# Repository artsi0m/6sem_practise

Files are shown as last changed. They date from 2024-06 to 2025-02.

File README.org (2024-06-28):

**  PCB project of RS485 — RS232 converter from 6 semester practise in BSUIR

| Folder             | Сontent                                      |
| kicad-rs-converter | PCB project in KiCAD                         |
| paper              | practise report                              |
| SEL                | structured element list (Перечень элементов) |

*** Original schematic

Original schematic was brought from Radio Locman magizine:
https://www.radiolocman.com/shem/schematics.html?di=64700
But DB9 connector was excluded.

Оригинальная схема была взята из журнала Радио Лоцман:
https://www.rlocman.ru/shem/schematics.html?di=64700
Однако разъём DB9 не использовался.

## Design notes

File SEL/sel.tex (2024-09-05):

\documentclass{xesel}
\usepackage{polyglossia}
\setdefaultlanguage{russian}
\setotherlanguage{english}
\defaultfontfeatures{Mapping=tex-text}
\setmainfont[AutoFakeSlant=0.25,AutoFakeBold=0.2,Scale=0.85]{OpenGost Type A TT}
\begin{document}
\XeselDesignedBy{Корякин А.Л. }
\XeselCheckedBy{Дубровский В.В. }
\XeselDocumentNumber{465223.013 ПЭ3}
\XeselDocumentName{Конвертер RS232 — RS485 \\
  с автоматическим управлением приемом/передачей}
\begin{xesel}
  \XeselHeader{Резисторы}
  \XeselEntry{R1, R2}{SMD 0603 1кОм 1/4 Вт}{2}{}
  \XeselEntry{R3...R6}{SMD 0603  2,2 кОм 1/4 Вт}{4}{}
  \XeselEntry{R7, R10}{SMD 0603 47 Ом 1/4 Вт}{2}{}
  \XeselEntry{R8, R9}{SMD 0603 560 Ом 1/4 Вт}{2}{}
  \XeselEntry{R11}{SMD 0603 120 Ом 1/4 Вт}{1}{}
  \XeselEntry{}{}{}{}
  \XeselHeader{Конденсаторы}
  \XeselEntry{C1, C2, C7, C8}{SMD 1206 1 мкФ}{4}{}
  \XeselEntry{C3, C5}{SMD 1206 10 мкФ}{2}{}
  \XeselEntry{C4, C6}{SMD 1206 100 нФ}{2}{}
%  \XeselEntry{C7, C8}{SMD 1206 1 мкФ}{2}{}
  \XeselEntry{}{}{}{}
  \XeselHeader{Колодки клеммные}
  \XeselEntry{X1}{1x02 PT-1,5-2-5.0-H  P5.00mm}{1}{} 
  \XeselEntry{X2}{1x03 PT-1,5-3-5.0-H  P5.00mm}{1}{} 
  \XeselEntry{X3}{1x02 PT-1,5-2-5.0-H  P5.00mm}{1}{} 
  \XeselEntry{}{}{}{}
  \XeselHeader{Микросхемы}
  \XeselEntry{DA1}{MAX232 SO-16 P1.27mm}{1}{}
  \XeselEntry{DA2}{LM7805 TO-252-2}{1}{}
  \XeselEntry{DA3}{MAX485 SO-8 P1.27mm}{1}{}
  \XeselEntry{}{}{}{}
  \XeselHeader{Светодиоды}
  \XeselEntry{HL1}{SMD 1210 Красный}{1}{}
  \XeselEntry{HL2}{SMD 1210 Зелёный}{1}{}
  \XeselEntry{}{}{}{}
\end{xesel}
\end{document}

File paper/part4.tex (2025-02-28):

\section{Программные средства моделирования \\
  и автоматизированного проектирования \\
  конструкций РЭС}

% KiCAD

Из-за приверженности к
свободному программному обеспечению ~\cite{GNU-philosophy},
мною была выбрана САПР
с открытым исходным кодом \textit{KiCAD} ~\cite{kicad-license}.

Для меня такой выбор связан,
этическими соображениями, которые,
будучи кратко сформулированы,
звучат как:

Если пользователи не контролируют программу,
программа контролирует пользователей ~\cite{ufair-nonfree-programs}.

% PCB doc screenshot

\begin{figure}[H]
  \centering
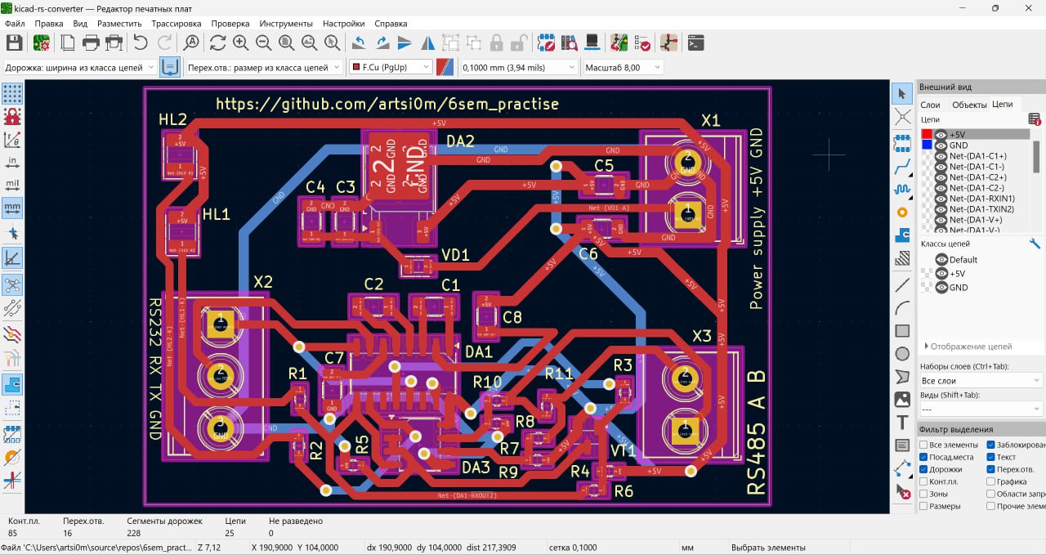
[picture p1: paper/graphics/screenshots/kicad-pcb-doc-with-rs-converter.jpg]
  
  \caption{Снимок экрана с ПП открытой в kicad-pcbdoc}
\end{figure}

Эта программа, ныне одно из самых передовых решений,
среди всех свободных САПР ПП.

Примечательно также, что его разработку спонсировал
Европейский Институт Ядерных Исследований ~\cite{kicad-sponsors}.

Другая причина выбора данной САПР при разработке,
используемый в ней, текстовой формат файлов,
при котором данные в документах САПР представлены
не иначе как Эс-Выражения (англ. \textit{S-Expressions})
~\cite{kicad-sexpr}.

В отличие от бинарных файлов,
используемых в \textit{Altium Designer},
файлы созданные при разработке печатной платы,
в \textit{KiCAD} за счёт их использования текста
возможно разместить в репозитории git.

Git это распределённая система контроля версий 
исходного кода \cite{git-dvcs}.

Из-за формата,
файлы \textit{KiCAD} могут быть обработаны,
как исходный код.
Это даёт возможность удобной кооперации, при совместной работе.

\begin{figure}[H]
  \centering
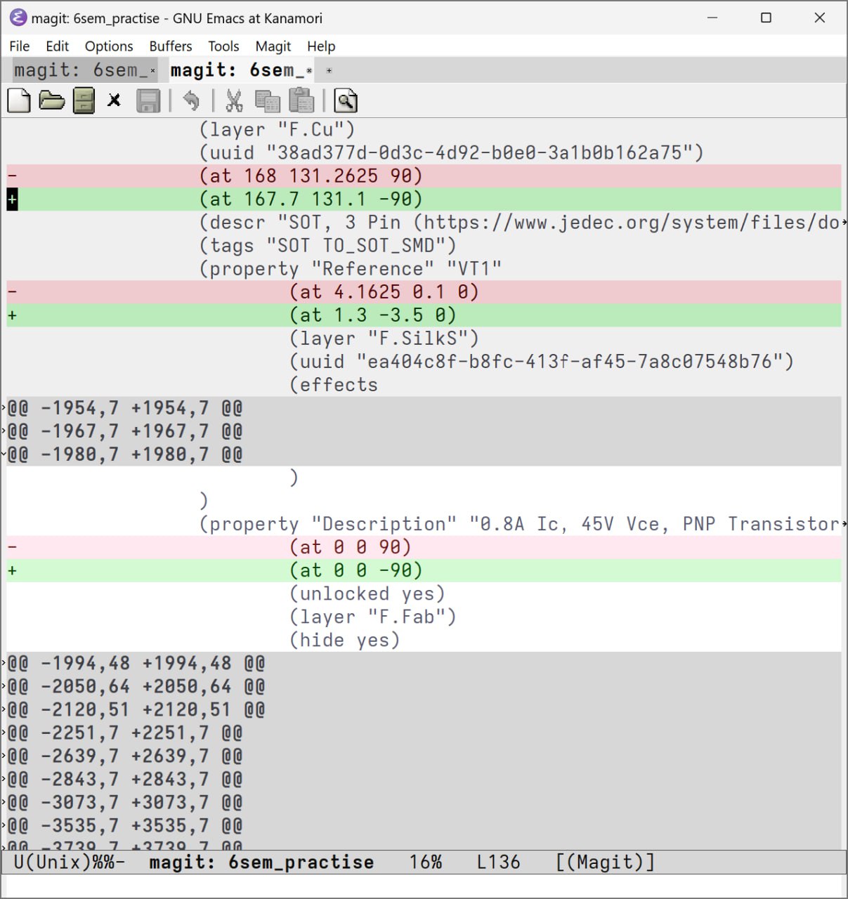
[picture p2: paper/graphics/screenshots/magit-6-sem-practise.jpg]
  
  \caption{Снимок экрана с окном magit,
    установленный в расширяемый редактор текста GNU/Emacs
    клиент системы контроля версий git.
    Видно, как magit может распознать изменения файла трассировки печатной платы,
    как добавление и удаление строк.}
\end{figure}

Например в едимном репозитории печатной платы,
один конструктор в соотвествующем файле
создаёт принципиальную схему устройства,
а другой в свою очередь, синхронизировав файл
через \textit{git} , используя готовую схему
трассирует печатную плату.

Более того, используя, так называемый монорепозиторий, как подход работы с \textit{git},
в одном репозитории можно содержать как печатную плату,
так и исходный код прошивки микроконтроллера,
используемый в ней.

В данной САПР было осуществлено создание
принципиальной cхемы устройства,
а также трассировка печатной платы, на основе связей между элементами,
импортированных из схемотехнической
части программы \textit{kicad-eeschema} ~\cite{kicad-doc-eeschema}.

% SimulIDE, KTechLab Proteus

Во момент работы над принципиальной схемой, была
допущена ошибка, из-за которой транзистор,
был подключен не теми выводами,
которые были обозначены на взятой изначально принципиальный схеме.

О своей оплошности я был осведомлён уже в тот момент,
когда выслал файлы по почте в отдел производство.
Я был проинформирован о недочёте в схеме начальником производственного отдела.
Это дало мне ценный урок:
при любых сомнениях в схемотехнической части разрабатываемого устройства,
следует провести тестирование в САПР симуляторе.

Среди изученных мною ранее
таковой является \textit{Proteus} ~\cite{Proteus-Simulation}. Её аналог в мире свободного ПО - \textit{SimulIDE} ~\cite{SimulIDE}.
%

%\begin{figure}[H]
%  \centering
%  \includegraphics[scale=0.35]{SimulIDE.png}
%  \caption{Снимок экрана с окном САПР-симулятора SimulIDE}
%\end{figure}

Для разработки данной печатной платы было достаточно
использование САПР ПП \textit{KiCAD},
однако стоит отметить, что использование специальных САПР симуляторов,
например \textit{Proteus} или \textit{KiCAD} существенно бы ускорило,
процесс изготовления и введения устройства в эксплуатацию
за счёт экономии времени на этапе исправления ошибок в принципиальной схеме.

\newpage

% Local Variables:
% compile-command: "sh build.sh"
% End:

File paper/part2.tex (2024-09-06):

\section{Этапы проектирования конструкции РЭС и их характеристика}

Во время работы в малом предприятии трудно заметить
четкие границы перехода между этапами конструирования РЭС,
так как процесс разработки, кроме того, что увлекателен сам по себе,
в данном случае, ещё и не усложнён бюрократической волакито.

Существует, по крайней мере, два способа
провести разделение процесса проектирования
на этапы:

\begin{enumerate}
\item По стадиям разработки конструкторской документации;
\item По стадиям работы в САПР.
\end{enumerate}

Обычно,
в технической литературе, приводится минимум пять стадий
разработки
конструкторской документации ~\cite{Rotkop1976}.

Эти стадии включают в себя:

\begin{enumerate}
\item Техническое задание
\item Техническое предложение
\item Эскизный проект
\item Технический проект
\item Выпуск рабочей документации
\end{enumerate}

Техничское задание я получил в устном виде от работников отдела.

Техническим предложением можно считать
исходную схему из журнала «Радио Лоцман».

Эскизный тогда это моя принципиальная схема и определенный в \textit{KiCAD}
формфактор платы.

Техничский проект это получившаяся в результате трассировки печатная плата.

Тогда выпуском рабочей документации — это переделанная,
в результате правок от отдела производства,
принципиальная схема и печатная плата.

Стадии работы в САПР, я бы описал следующим образом:
\begin{enumerate}
\item Создание библиотеки схемных элементов и библиотеки посадочных мест.
\item Создании принципиальной схемы со связями между элементами.
\item Верификация принципиальной схемы \textit{ERC}
  и экспорт связей в часть САПР, предназначенную для трассировки
  % Electric Rule Checker.
\item Трассировка печатной платы и верификация правил  \textit{DRC}.
  % Design Rule Checker
\end{enumerate}

Первый этап работы в САПР мною был пропущен,
по той причине, что kicad обладает большой встроенной
библиотекой посадочных мест.

% Сюда скриншот окна со встроенной библиотейкой посадочных мест

\begin{figure}[H]
  \centering
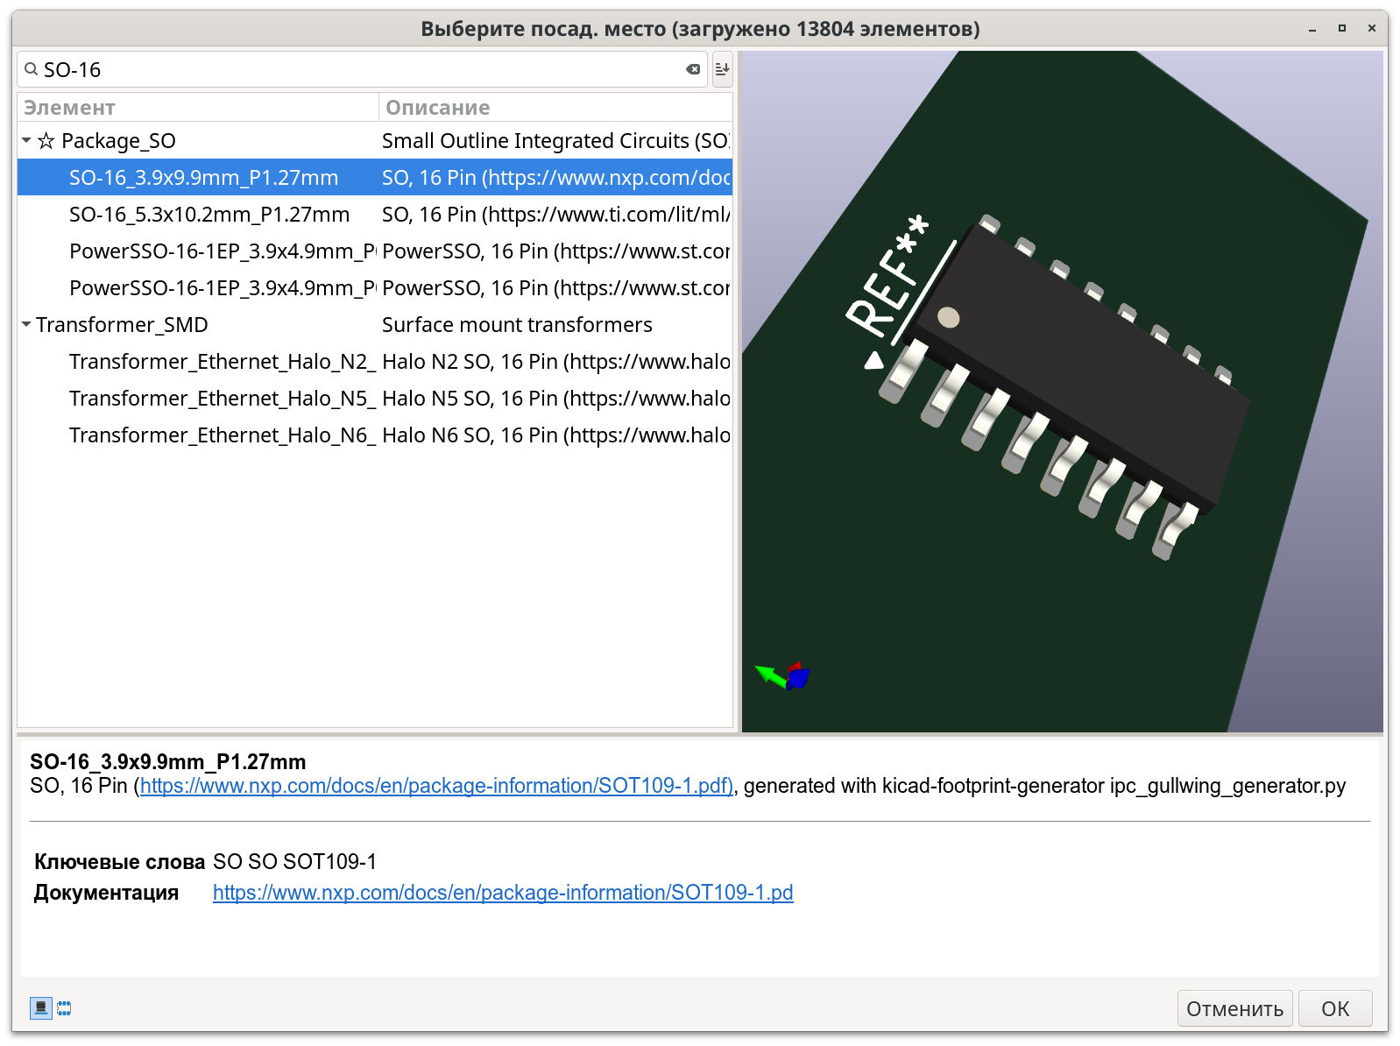
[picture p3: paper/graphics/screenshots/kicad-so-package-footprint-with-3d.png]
  
  \caption{Снимок экрана с меню выбора посадочных мест в \textit{kicad-pcbdoc}}
\end{figure}

Также была использована готовая
схемная библиотека, выполненная в рамках стандартных УГО. 
% https://github.com/KiCad-RU/kicad-symbols-gost

% Скриншот окна со схемной библиотекой по ГОСТ
\begin{figure}[H]
  \centering
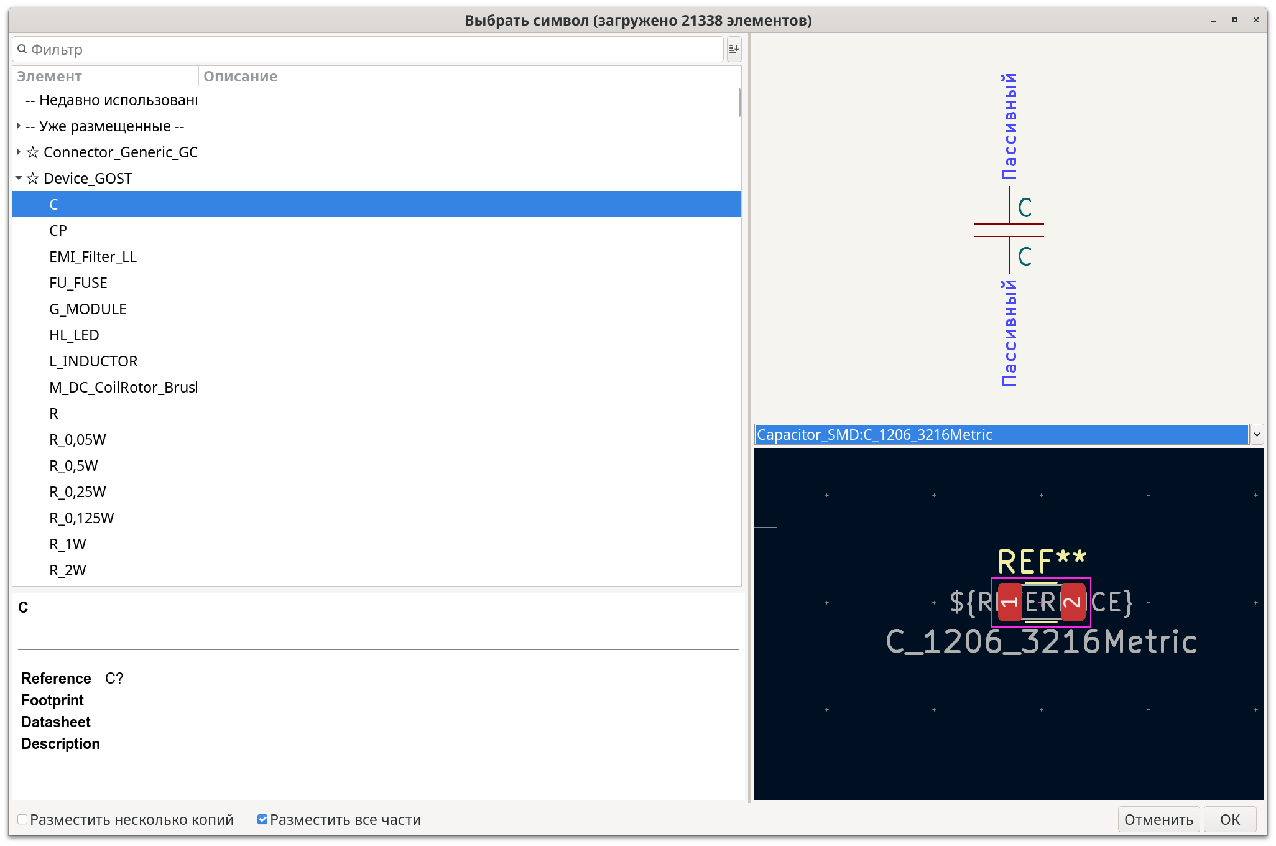
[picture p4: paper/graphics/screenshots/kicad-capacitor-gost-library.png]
  
  \caption{Снимок экрана с меню выбора cхемных компонентов
    мест в \textit{kicad-eeschema}}
\end{figure}

После долгой работы над схемой, её верификация \textit{ERC}
не показывала предупреждений о нарушении.

Спустя несколько дней к такому же результату,
я пришел выполняя верификацию разведённой печатной платы \textit{DRC}.

Однако верификация не уберегла,
от ошибки:

Неправильного включения транзистора на принципиальной схеме.

Помочь могло либо внимание к сложным местам,
потому что именно место, где я допустил ошибку,
изначально казалось самым сложным, как в создании схемы,
так и в трассировке платы. Либо использования специальной САПР симулятора.

\newpage

% Local Variables:
% compile-command: "sh build.sh"
% End:

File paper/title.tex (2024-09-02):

%%% Local Variables: 
%%% coding: utf-8
%%% mode: latex
%%% TeX-engine: xetex
%%% End:

%%% Титульный лист
\begin{titlepage}
  % Устаналиваем стиль ESKD empty, иначе на титульнике будет стоять
  % номер страницы. Потому что в классе bsuir-std я включил нумерацию.
\begin{center}
Министерство образования Республики Беларусь\\[1.2em]
Учреждение образования\\[0.4em]
БЕЛОРУССКИЙ ГОСУДАРСТВЕННЫЙ УНИВЕРСИТЕТ ИНФОРМАТИКИ И РАДИОЭЛЕКТРОНИКИ\\[2.0em]
\end{center}

\begin{flushright}
  \begin{minipage}{0.5\textwidth}
    Номер зачетной книжки\\
    Руководитель курсового проекта\\

    \underline{\hspace*{2.8cm}} В.\,А.~Ящук\\
    \underline{\hspace*{1.4cm}}.\underline{\hspace*{1.4cm}}.2024
  \end{minipage}\\[2em]
\end{flushright}

\begin{center}
\textbf{ОТЧЕТ}\\
\textbf{по производственной практике}\\
Место прохождения практики: ООО «РТЕ Сервис», г.Минск\\
Сроки прохождения практики: 10.06.2024 по 07.07.2024\\
\end{center}

\begin{center}
  \textbf{ПОЯСНИТЕЛЬНАЯ ЗАПИСКА}\\
  к курсовому проекту\\
  на тему\\[2.0em]

  \textbf{СИСТЕМА ТЕСТИРОВАНИЯ СЕРВОПРИВОДОВ КВАДРОКОПТЕРА}\\
  БГУИР КП% 1-39 02 01 013 ПЗ
\end{center}

\begin{flushright}
    \begin{minipage}{9.3cm}
        Студент:  гр. 112601 Корякин~А.~Л.\\[0.1em]

        Курсовой проект представлен на проверку: \underline{\hspace*{1.4cm}}.\underline{\hspace*{1.4cm}}.2024\\
        \underline{\hspace*{5.6cm}}
        
    \end{minipage}
  \end{flushright}
  
  \vfill
  \begin{center}
    {\normalsize Минск 2024}
    \end{center}
\end{titlepage}

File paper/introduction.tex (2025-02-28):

\tableofcontents
\newpage

\section*{Введение}
\addcontentsline{toc}{section}{Введение}

Целью прохождения практики является получение
навыков и опыта реальной работы на предприятии.

Основной задачей решаемой на данной практике было
создание печатной платы радиоэлектронного средства:
«Конвертер RS-232 - RS-485 с автоматическим управлением приемом-передачей.»

Данное устройство было разработано и цель практики была достигнута.

\newpage

\section*{Перечень условных обозначений,
  символов и терминов}
\addcontentsline{toc}{section}{Перечень условных обозначений, символов и терминов}

АСКУЭ — автоматизированная система контроля и учета электроэнергии.

ГОСТ — государственный стандарт.

РЭС - радиоэлектронное средство.

САПР — системы автоматизированного проектирования.

ИВК — измерительно вычислительный комплекс.

УСПД — устройство сбора и передачи данных.

\textit{ERC} — Electric Rule Checker

\textit{DRC} — Design Rule Checker

\newpage

%% Local Variables:
%% compile-command: "sh build.sh"
%% End:

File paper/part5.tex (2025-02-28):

\section{Проектные решения конструкции РЭС}

\subsection{Обоснование актуальности разработки \\
  электронного модуля}

В ходе совещания с работниками отдела,
мною был предложен вариант,
когда, основываясь на требованиях сотрудников данного
отдела, я, создаю конструкторскую документацию,
на производство РЭС, ошибки в создании которого не скажутся
экономически на благополучии фирмы,
но при этом факт успешного изготовления
единичного экземпляра или их пары устройств,
существенно упростил бы работу одного из отделов.

Писать код для ИВК или модернизировать коммуникаторы,
а уж тем более счётчики мне бы не доверили по причине
малого опыта. Поэтому, ко мне пошли на встречу, когда
я предложил выполнить что-то более простое,
но тем не менее полезное отделу сервиса,
в котором я был занят прохождением практики.

Разработка данного радиоэлектронного средства обоснована
так как оно, существенно упрощает
работу отдела сервиса.

Однако, я тоже сыграл свою роль в решение о выборе технического задания.
Дело в том, что компания ООО «РТЕ Сервис» занята производством
оборудования, для которого высока цена ошибки.
Основываясь на этом,
я стремился выбрать проект,
который,
при выполнение с ошибками не принёс бы значительного,
но тем не менее, был бы полезен нескольким работникам предприятия.

\subsection{Составление технического задания\\
  на модернизацию электронного модуля}

Из-за того, 
что я проходил практику не в отделе производства,
а под начальством сотрудников отдела сервиса,
техническое задание на РЭС,
было сформулировано работниками сервиса
в устной форме, исходя из требований этого отдела.

Согласно озвученному техническому заданию,
была взята готовая схема преобразователя интерфейсов
\textit{RS-232 - RS-485} из
журнала «Радио Лоцман» ~\cite{rlocman-rs-converter}.

\begin{figure}[H]
  \centering
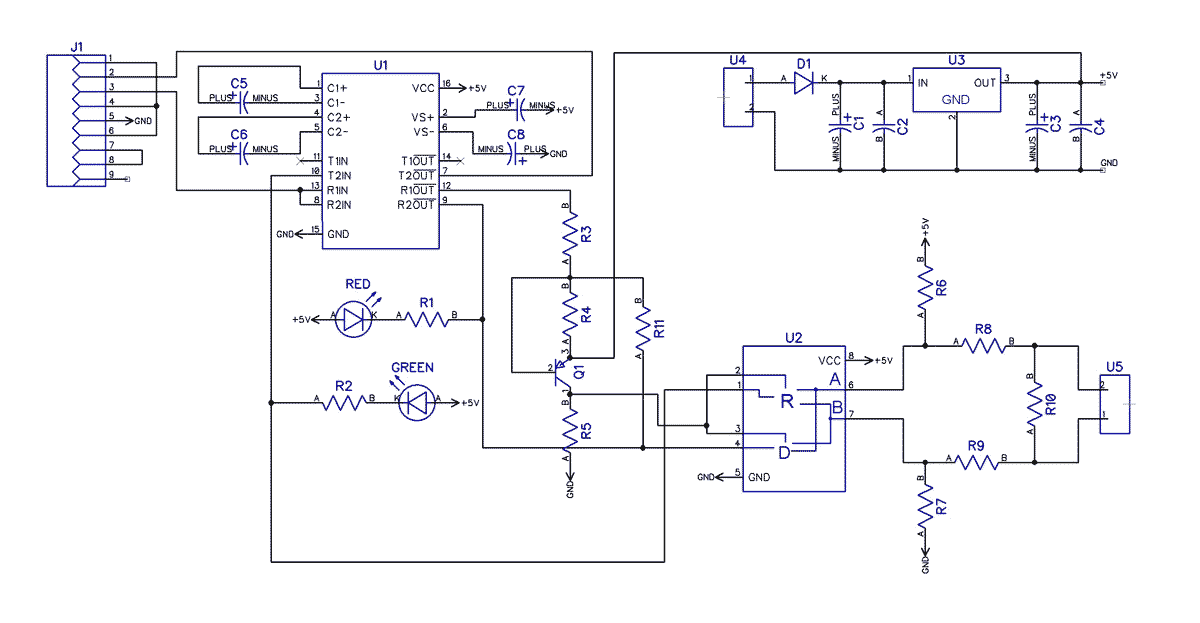
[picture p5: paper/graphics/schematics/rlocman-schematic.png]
  
  \caption{Схема представленная на сайте журнала «Радио Лоцман»}
\end{figure}

Модернизация заключалась в том,
что на готовой схеме разъём \textit{DB9}
со стороны включения интерфейса \textit{RS-232}
был заменён на клемму с тремя разъёмами.

Такой выбор был сделан на основании
желания сотрудников раздела
упростить подключение счётчика с интерфейсом \textit{RS-485} к ПК.

Более того: разъём \textit{DB9}
содержит избыточное количество
пинов для подключения по интерфейсу \textit{RS-232}.

Конечно же, существуют разные версии стандарта этого интерфейса,
но в минимальной и достаточной комплектации,
необходимы всего три пина:
\begin{itemize}
\item RX
\item TX
\item GND
\end{itemize}

Сам по себе данный стандарт — уточнение
стандарта \textit{UART} и часто, в литературе может быть упомянут как
последовательный порт компьютера.

Недостаток данного интерфейса, в том,
что в отличие от \textit{RS-485}
он не предназначен для передачи данных на дальнее расстояние.
По этой причине на многих старых счетчиках,
изготовленных вне ООО «РТЕ Сервис» был
использован именно этот интерфейс,
как часто вариант размещения,
когда коммуникатор был размещён в одному шкафу с счётчиком,
был недоступен.
В такой ситуации требовалась передача данных на более дальнее расстояние.
И это именно тот случай, когда интерфейс
основанный на принципе работы витой пары,
подходит как никак лучше.

\subsection{Пояснение схемы электрической принципиальной\\
  электронного модуля}

В ходе модернизации схемы её принцип работы не изменился.

Схема, питаемая от блока питания с напряжением пять Вольт
и преобразует сигнал идущий по интерфейсу
стандарта \textit{RS485} в сигнал идущий по интерфейсу
стандарта \textit{RS232}.

%\begin{figure}[H]
%  \centering
%  \includegraphics[scale=0.4]{kicad-rs-converter-sch.pdf}
%  \caption{Переработанная, в ходе практики, принципиальная схема.}
%\end{figure}

Во время передачи данных микросхема ~\textit{MAX232} преобразует сигнал,
пришедший с клеммы обозначенной,
как «X2» в уровни TTL/CMOS.
Затем микросхема ~\textit{MAX485}
передает этот сигнал в линию \textit{RS-485}, как разность напряжений.
При приеме данных микросхема \textit{MAX485} обнаруживает наличие данных
на линии \textit{RS-485} и передает их микросхеме \textit{MAX232},
после чего сигнал поступает на клеммы.

Красный светодиод показывает передачу,
зеленый – прием данных.

Чтобы обеспечить постоянный уровень напряжения на линии,
когда передача данных не осуществляется,
к ней подключены два резистора.
Один, подключен к напряжению питания, другой к общему проводу ~\cite{rlocman-rs-converter}.

Конвертер управляет режимом приема и передачи автоматически.

\subsection{Выбор элементов и комплектующих изделий\\
  для электронного модуля входящего в состав РЭС}

Все элементы, использованные в печатной плате были \textit{SMD}
компонентами.

Во время работы со схемной библиотекой соотвествующей ГОСТ
был найден список аналогичных \textit{MAX232} и \textit{MAX485} отечественных
микросхем.

Однако строгих требований на предприятии,
к набору элементов на данном устройстве не преъявляли
и потому были использова номенклатура компоентов,
посадочные места которых,
оказались в стандартной поставке \textit{KiCAD}.
Однако даже их число можно считать весомым.

\subsection{Конструкторское проектирование электронного модуля}

Конструкторское проектирование электронного модуля заключалось в
создание печатной платы в САПР \textit{KiCAD} и её трассироваке.
Для соедениения контактных дорожек,
в печатной плате использовались две стороны.

Толщина платы 1,6мм.

Печатная плата изготавливалась,
в соотвествии с техническим заданием,
в котором не оговаривалось создание монтажных отверстий и корпуса.

\subsection{Компьютерные программы используемые\\
  для конструкторского проектирования}

При создании печатной платы была использована САПР \textit{KiCAD}.
% FreeCAD, SolidWorks
% FlatCAM

Поскольку корпус для печатной платы не разрабатывался,
говорить о работе в машиностроительных САПР не приходится.

\newpage

% Local Variables:
% compile-command: "sh build.sh"
% End:

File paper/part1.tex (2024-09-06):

\section{Структура и деятельность служб предприятия}

Компания ООО «РТЕ Сервис» 
предлагает широкий диапазон услуг и оборудования, для АСКУЭ ~\cite{rte-about}.

На сегодняшний день компания предлагает
большой перечень оборудования собственного производства
от приборов учета электроэнергии,
до комплексов, созданных для экономии потребления энергоресурсов ~\cite{rte-about}.

Приоритетное направление деятельности компании – создание и внедрение комплексных систем учета,
для отечественного рынка  ~\cite{rte-about}.

На момент прохождения мною практики
в нём работало суммарно не более 15 человек.
Из чего следует вывод,
что данная компания относится к классу малых предприятий ~\cite{mal-biznes-ru}.

Данная компания занимается, как производством оборудования,
так и обслуживанием его.

Из этого факта можно провести структурное разделение компании
по следующему принципу:
\begin{itemize}
\item Отдел кадров.
\item Отдел сервиса.
\item Отдел производства.
\end{itemize}

Географически же, предприятие располагалось таким образом,
что отдел кадров располагался в Минске. Отдел сервиса,
находился с отделом кадров в одном помещении, а отдел
производства был расположен в городе Молодечно.

Таким образом вышло,
что я проходил практику под начальством не кого-либо из отдела производства,
а при отделе сервиса.

Отдел сервиса, в котором я проходил практику, кроме того,
что отвечал на звонки пользователей УСПД и работал с
ИВК «Энергобаланс» был занят отладкой отказавшего
оборудования.

Зачастую это было и оборудование изначально произведённое
какой-то другой компанией.

\newpage

% Local Variables:
% compile-command: "sh build.sh"
% End:

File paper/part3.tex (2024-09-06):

\section{Проектная документация для РЭС}

\subsection{Перечень и характеристика\\
  основных конструкторских документов}

Поскольку,
данное радиоэлектронное средство,
используется в условиях работы в закрытом, проветриваемом помещении,
можно считать, что условия работы описаны в ГОСТ-15150-69,
разделе УХЛ 4.2 ~\cite{GOST-15150-69}.

Исходя из этого стандарта и технического задания,
было решено выбрать вариант исполнения устройства,
при котором как таковой отсутствует корпус.

Опираясь на стандарты ГОСТ 2.108-68 ~\cite{GOST-spec}
% gost spec
и ГОСТ 2.702-2011 ~\cite{GOST-2-702-2011} можно прийти к выводу,
% gost SEL
что заполнение спецификации в данном проекте РЭС не требуется,
по той причине, что устройство является отдельной печатной платой,
а не составной сборочной единицей,
состоящей из корпуса, печатной платы,
отдельных крепежных изделий.

Ровно по этой же причине не был создан сборочный чертёж .

Такое строение было обусловлено техническим заданием на РЭС.

При выполнении конструкторской документации,
были, в обязательном порядке, использованы следующие ГОСТ:
\begin{enumerate}
\item ГОСТ 2.702 «Электрические схемы»  
\item ГОСТ 2.701 «Виды»                 
\item ГОСТ 2.104 «Основные надписи»     
\item ГОСТ 2.743 «УГО Цифровых схем»    
\item ГОСТ 2.759 «УГО Аналоговых схем»  
\end{enumerate}

Однако стоит отметить, что на предприятии никто не ожидал
строгого следования ГОСТ, касающегося непосредственно
принципиальной схемы.

В приорете было скорее правильное изготовление печатной платы.

Основываясь на этом,
я уделял более пристальное внимание стандартам выполнения печатной платы IPC.

А именно ограничениям, 
на минимальную ширину дорожки и зазор между ними.

\subsection{Основные правила выполнения схем}

Основное правило выполнения схемы, согласно ГОСТ:
Сигнал идёт по схеме слева направо ~\cite{GOST-2-702-2011}.
% GOST-schematic-main — тот ГОСТ, где сказано, что сигнал идёт слева направо.
И согласно этому правилу разъём питания был размещён с левой стороны схемы.
Это правило также влияет,
на работу в САПР так,
что на этапе создания принципиальной схемы,
автоматическая аннотация элементов схемы осуществляется,
слева-направо, сверху-вниз.
Это режим аннотации,
выбирается в настройках САПР.
% CЮДА можно вставить скриншот с окном из KiCAD.

При разработке принципиальной схемы также важна согласованность,
так, на схеме не могут быть выставлены номиналы только у части
элементов.
Обозначения номиналов должно либо отсутствовать,
либо присутствовать у каждого элемента. При условии,
что это не мешает читаемости принципиальной схемы.

При этом,
единицы измерения номиналов не пишутся на схеме,
пишутся только обозначения коэффициентов.
Так резистор сопротивлением 47 Ом на схеме обозначается как «47», а
резистор сопротивлением 1 кОм, на схеме обозначается как «1к».

\subsection{Правила выполнения
  перечня элементов\\
  электрической принципиальной схемы}

Согласно ГОСТ ~\cite{GOST-2-702-2011} перечень
элементов был выполнен следующим образом:
Элементы в таблице составлены,
согласно своим обозначениям на схеме, в порядке английского алфавита,
а также с учётом увеличения номинала.
При этом была использована опция стандарта,
разрешающая вынесение резисторов и конденсаторов
в начало схемы, как элементов представленных
в самом большом количестве на схеме.

\subsection{Основные правила написания\\
  спецификации на сборочную единицу}

Принимая во внимание,
то что для данной РЭС не было необходимо создание спецификации,
можно, тем не менее добавить,
что основное различие в заполнение спецификации заключается в том,
что, перечень составляется так, что устройства располагаются в таблице,
согласно обозначениям элементов на схеме, расположенных по порядку латинского алфавита и номиналу,
в порядке возрастания ~\cite{GOST-spec}.

В спецификации
элементы расположены согласно своему названию по порядку
кириллического элемента. При этом, при описании элемента,
сначала выписывается имя существительное, а затем имя прилагательное.

Пример: «Резистор Подстроечный» или «Резистор Переменный».

Спецификация в общем случае состоит из разделов,
которые располагают в следующей последовательности ~\cite{GOST-spec}:
\begin{enumerate}
\item Документация;
\item Комплексы;
\item Сборочные единицы;
\item Детали;
\item Стандартные изделия;
\item Прочие изделия;
\item Материалы;
\item Комплекты.
\end{enumerate}

Также отличается сам формат таблицы спецификации отличается от таблицы перечня.

\newpage

% Local Variables:
% compile-command: "sh build.sh"
% End:

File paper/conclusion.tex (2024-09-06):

\section*{Заключение}
\addcontentsline{toc}{section}{Заключение}

В результате прохождения практики было разработано устройство
«Конвертер RS-232 - RS-485 в автоматическим управлением приемом передачей».

Проведена модернизация данного устройства.

Разработана новая схема электрическая принципиальная,
перечень элементов платы.
разработана печатная плата и готовы файлы для её производства.

\newpage

\renewcommand{\refname}{\textbf{Cписок использованных источников}}
\DeclareFieldFormat{url}{Режим доступа\addcolon\space\url{#1} [Электронный ресурс].}
\DeclareFieldFormat{title}{{#1}}
\DeclareFieldFormat{labelnumberwidth}{[{#1}]\adddot  }
\addcontentsline{toc}{section}{Список использованных источников}
\printbibliography

\newpage

% Local Variables:
% compile-command: "sh build.sh"
% End:

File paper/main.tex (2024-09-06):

%%% Local Variables: 
%%% compile-command: "sh build.sh" 
%%% End: 
%%% coding: utf-8
%%% mode: latex
%%% TeX-engine: xetex
%%% End:

% main.tex файл который компилируется и подключает за собой остальный
% файлы с содержимым через input
% При этом согласно моей же логике преамбула должна отстаться здесь.

% Используем опцию emptystyle т.к. bsuir-std расширяет eskdxtext,
% который без этой опции сделает рамку для чертежа даже на документе
% с просто текстом.
\documentclass[a4paper]{bsuir-std}

\usepackage[sorting=none,backend=biber]{biblatex}
% библиогорафия в last
\usepackage{url}

\usepackage{float}

\addbibresource{Karakin6semPractise.bib}

\begin{document}
% Путь к месту где картинки лежат
\graphicspath{ {graphics/screenshots}
  {graphics/schematics}}
% https://tex.stackexchange.com/a/139403

%%% Титульник
%%% \input{title} %%% I already have one this time

%%% Введение.
\input{introduction}

\input{part1}

\input{part2}

\input{part3}

\input{part4}

\input{part5}

\input{conclusion}
\end{document}

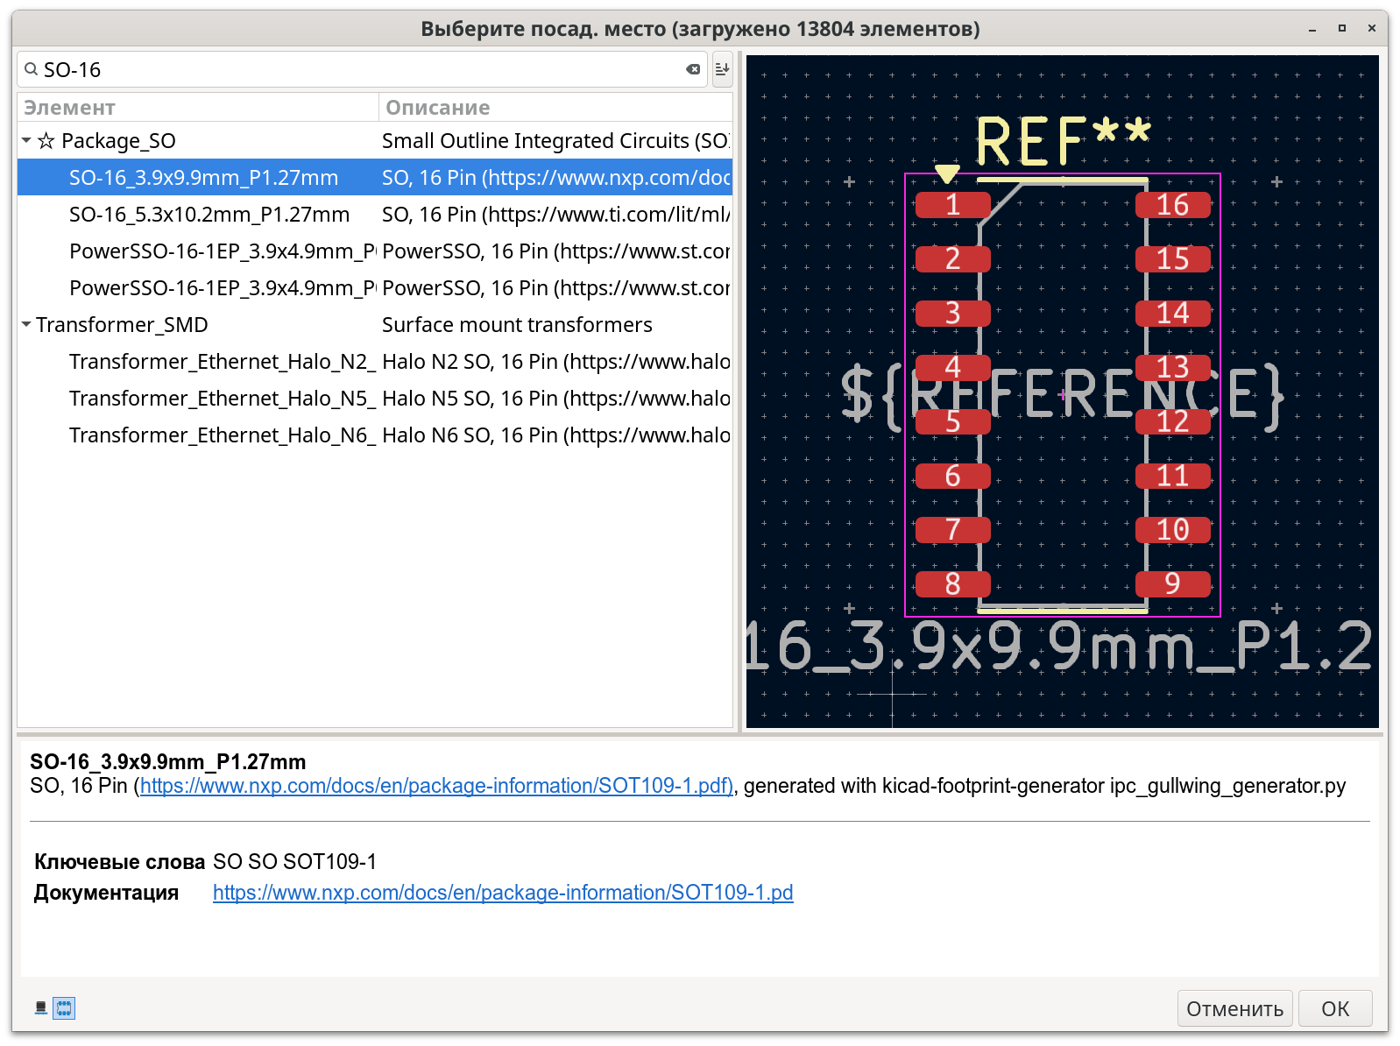
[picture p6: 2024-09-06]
paper/graphics/screenshots/kicad-so-package-footprint.png

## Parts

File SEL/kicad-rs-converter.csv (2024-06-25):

Id | Designator | Footprint | Quantity | Designation | Supplier and ref
1 | C8,C2,C7,C1 | C_1206_3216Metric | 4 | 1мк
2 | R7,R10 | R_0603_1608Metric | 2 | 47
3 | R9,R8 | R_0603_1608Metric | 2 | 560
4 | R3,R5,R6,R4 | R_0603_1608Metric | 4 | 2к2
5 | X2 | TerminalBlock_Phoenix_PT-1,5-3-5.0-H_1x03_P5.00mm_Horizontal | 1 | CONN_RS232
6 | VT1 | SOT-23 | 1 | BC807
7 | DA1 | SO-16_3.9x9.9mm_P1.27mm | 1 | MAX232_GOST
8 | C3,C5 | C_1206_3216Metric | 2 | 10мк
9 | X3 | TerminalBlock_Phoenix_PT-1,5-2-5.0-H_1x02_P5.00mm_Horizontal | 1 | CONN_2
10 | R11 | R_0603_1608Metric | 1 | 120
11 | R1,R2 | R_0603_1608Metric | 2 | 1к
12 | DA2 | TO-252-2 | 1 | LM7805
13 | X1 | TerminalBlock_Phoenix_PT-1,5-2-5.0-H_1x02_P5.00mm_Horizontal | 1 | CONN_PWR
14 | VD1 | D_0805_2012Metric | 1 | VD
15 | C4,C6 | C_1206_3216Metric | 2 | 100н
16 | DA3 | SO-8_3.9x4.9mm_P1.27mm | 1 | MAX485
17 | HL1 | LED_1210_3225Metric | 1 | RED
18 | HL2 | LED_1210_3225Metric | 1 | GREEN

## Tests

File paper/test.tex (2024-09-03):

\section{TEST}
\subsection{subTEST}

\Blindtext

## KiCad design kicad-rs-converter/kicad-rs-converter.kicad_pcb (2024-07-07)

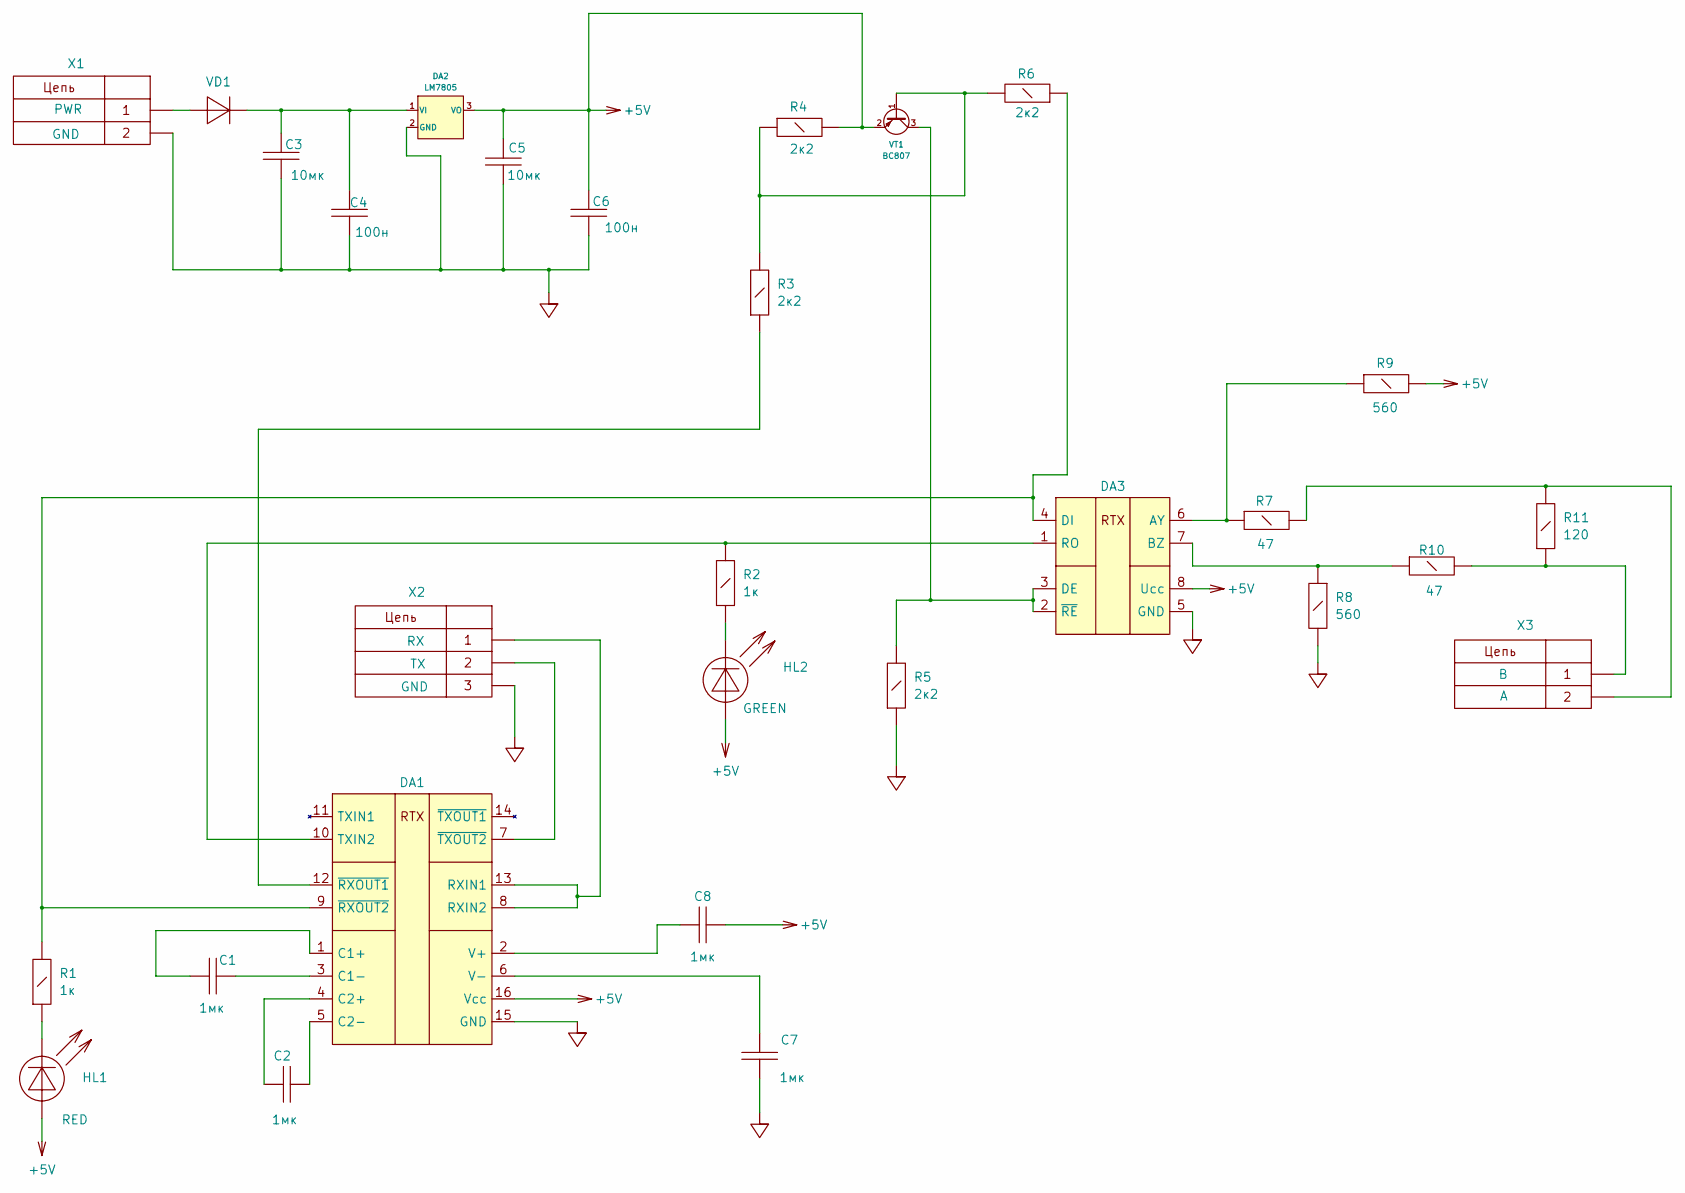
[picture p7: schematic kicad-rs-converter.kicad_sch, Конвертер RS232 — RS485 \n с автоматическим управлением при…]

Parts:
C1, C2, C7, C8: 1мк; C_1206_3216Metric
C3, C5: 10мк; C_1206_3216Metric
C4, C6: 100н; C_1206_3216Metric
DA1: MAX232_GOST; SO-16_3.9x9.9mm_P1.27mm
DA2: LM7805; TO-252-2
DA3: MAX485; SO-8_3.9x4.9mm_P1.27mm
HL1: RED; LED_1210_3225Metric
HL2: GREEN; LED_1210_3225Metric
R1, R2: 1к; R_0603_1608Metric
R3, R4, R5, R6: 2к2; R_0603_1608Metric
R7, R10: 47; R_0603_1608Metric
R8, R9: 560; R_0603_1608Metric
R11: 120; R_0603_1608Metric
VD1: VD; D_0805_2012Metric
VT1: BC807; SOT-23
X1: CONN_PWR; TerminalBlock_Phoenix_PT-1,5-2-5.0-H_1x02_P5.00mm_Horizontal
X2: CONN_RS232; TerminalBlock_Phoenix_PT-1,5-3-5.0-H_1x03_P5.00mm_Horizontal
X3: CONN_2; TerminalBlock_Phoenix_PT-1,5-2-5.0-H_1x02_P5.00mm_Horizontal

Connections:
+5V: C5.1, C6.1, C8.2, DA1.16 (Vcc), DA2.3 (VO), DA3.8 (Ucc), HL1.2 (A), HL2.2 (A), R4.2, R9.2, VT1.2 (E)
GND: C3.2, C4.2, C5.2, C6.2, C7.1, DA1.15 (GND), DA2.2 (GND), DA3.5 (GND), R5.1, R8.2, X1.2, X2.3
unnamed: C1.1, DA1.1 (C1+)
unnamed: C1.2, DA1.3 (C1-)
unnamed: C2.1, DA1.4 (C2+)
unnamed: C2.2, DA1.5 (C2-)
unnamed: DA1.8 (RXIN2), DA1.13 (RXIN1), X2.1
unnamed: DA1.10 (TXIN2), DA3.1 (RO), R2.2
unnamed: C8.1, DA1.2 (V+)
unnamed: C7.2, DA1.6 (V-)
unnamed: DA1.12 (~RXOUT1), R3.1
unnamed: DA1.9 (~RXOUT2), DA3.4 (DI), R1.2, R6.1
unnamed: DA1.7 (~TXOUT2), X2.2
unnamed: C3.1, C4.1, DA2.1 (VI), VD1.1 (K)
unnamed: DA3.6 (AY), R7.1, R9.1
unnamed: DA3.7 (BZ), R8.1, R10.1
unnamed: DA3.2 (~RE), DA3.3 (DE), R5.2, VT1.3 (C)
unnamed: HL1.1 (K), R1.1
unnamed: HL2.1 (K), R2.1
unnamed: R10.2, R11.1, X3.1
unnamed: R7.2, R11.2, X3.2
unnamed: VD1.2 (A), X1.1
unnamed: R3.2, R4.1, R6.2, VT1.1 (B)

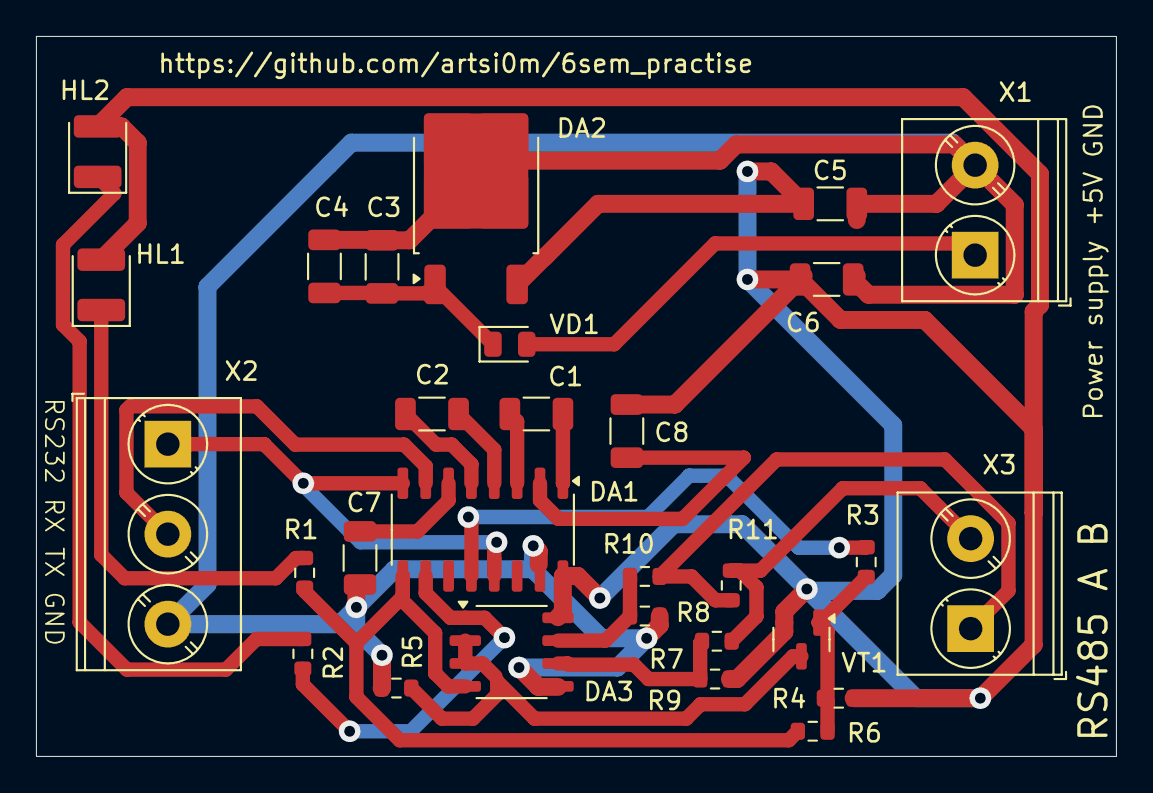
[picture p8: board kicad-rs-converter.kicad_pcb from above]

Board: 2 copper layers, 60.0 x 40.0 mm, 29 parts (0 on the bottom side), 23 nets.

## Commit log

2024-06-18 Initial commit with empty kicad project
    [kicad-rs-converter.kicad_pcb, kicad-rs-converter.kicad_sch]
2024-06-19 Рамка по ГОСТ
    [kicad-rs-converter.kicad_sch]
2024-06-19 Placed two XS's on scheme
    [kicad-rs-converter.kicad_sch]
2024-06-19 Filter out kicad lock files with gitignore
2024-06-19 Filter out kicad lock files with .gitignore attempt 2
2024-06-20 Placed MAX232 to the left as much as I could
    [kicad-rs-converter.kicad_sch]
2024-06-20 Part of the circuit with the second LED
    [kicad-rs-converter.kicad_sch]
2024-06-20 Created part of circuit with voltage regulator
    [kicad-rs-converter.kicad_sch]
2024-06-20 Created part of circuit with MAX485 only
    [kicad-rs-converter.kicad_sch]
2024-06-20 Placed MAX485 on the scheme
    [kicad-rs-converter.kicad_sch]
2024-06-20 Schematics almost done, all parts of circuit is on the scheme
    [kicad-rs-converter.kicad_sch]
2024-06-20 Fixed scheme, pwr connector named, RXOUT2 of MAX484 connected
    [kicad-rs-converter.kicad_sch]
2024-06-20 Write down surnames
    [kicad-rs-converter.kicad_sch]
2024-06-20 Scheme annotation
    [kicad-rs-converter.kicad_sch]
2024-06-20 Placed values on every element
    [kicad-rs-converter.kicad_sch]
2024-06-20 MAX232 and MAX485 in my own library
    [kicad-rs-converter.kicad_sch]
2024-06-20 Fixing errors from ERC
    [kicad-rs-converter.kicad_sch]
2024-06-20 ERC fix with PWR_flag, PWR_CONN in sym_lib, package for MAX232 assigned
    [kicad-rs-converter.kicad_sch]
2024-06-20 BC327 to BC807 smd, SOT-23, set most of the scheme to smd.
    [kicad-rs-converter.kicad_sch]
2024-06-21 A4 to A3, because of the GOST norms for sheet
    [kicad-rs-converter.kicad_sch]
2024-06-21 Created separate connector symbol for RS232
2024-06-21 Schematic redone on A3
    [kicad-rs-converter.kicad_sch]
2024-06-21 Assigned values almost everywhere, writing sheet
    [kicad-rs-converter.kicad_sch]
2024-06-21 ESKD class assigned
    [kicad-rs-converter.kicad_sch]
2024-06-21 footprints for MAX232 & MAX485
    [kicad-rs-converter.kicad_sch]
2024-06-21 Placed footprints for LED
    [kicad-rs-converter.kicad_sch]
2024-06-21 Placed footprints for Resistors
    [kicad-rs-converter.kicad_sch]
2024-06-21 Placed footprints for polar capacitors
    [kicad-rs-converter.kicad_sch]
2024-06-21 Footprint for SMD Capacitors and Resistors
    [kicad-rs-converter.kicad_sch]
2024-06-24 Changed from polar CP capacitors to regular capacitors C
    [kicad-rs-converter.kicad_sch]
2024-06-24 Assigned footprint of SMD:C_1206_3216 Metric to every capacitor
    [kicad-rs-converter.kicad_sch]
2024-06-24 Assigned footprints for X connector — Terminal Block
    [kicad-rs-converter.kicad_sch]
2024-06-24 Imported footprints from schematics into PCB layout
    [kicad-rs-converter.kicad_pcb]
2024-06-24 Assigned netclasses and colors for cicuits
    [kicad-rs-converter.kicad_pcb]
2024-06-24 Drawing edge cuts
    [kicad-rs-converter.kicad_pcb]
2024-06-24 PCBdoc: everything connected except for GND and +5V
    [kicad-rs-converter.kicad_pcb]
2024-06-24 pcbdoc finished, but some parts can be done better.
    [kicad-rs-converter.kicad_pcb]
2024-06-24 Made PCB layout on 70x40mm board
    [kicad-rs-converter.kicad_pcb]
2024-06-24 Moved transistor BC807 and redone PCB layout a little bit.
    [kicad-rs-converter.kicad_pcb]
2024-06-24 Rebuild from scratch. 0.8 track_width and 60x40mm board
    [kicad-rs-converter.kicad_pcb]
2024-06-25 Exported bom
    [kicad-rs-converter.csv]
2024-06-25 Начал перечень писать
2024-06-25 More resistors
2024-06-25 README with kicad-rc-converter, paper, SEL folders mentioned
2024-06-28 Silkscreen added on pcb
    [kicad-rs-converter.kicad_pcb]
2024-06-28 Link to original schematic + formatted
2024-07-01 Fixed DRC error from silkscreen plaeced near footprint
    [kicad-rs-converter.kicad_pcb]
2024-07-06 There is an error, PWR_FLAG removed to see if fixing would fix ERC
    [kicad-rs-converter.kicad_sch]
2024-07-06 The fix consisted of flipping transistor
    [kicad-rs-converter.kicad_sch]
2024-07-07 trying to make place with error more readable
    [kicad-rs-converter.kicad_sch]
2024-07-07 transistor flip and reconnect on pcbdoc
    [kicad-rs-converter.kicad_pcb]
2024-07-08 Fix the Surname of the one who checks the work
    [kicad-rs-converter.kicad_sch]
2024-09-02 СТП part into class, comments and separation in sections
2024-09-06 Листы по СТП, флоаты (картинки, таблицы) по номерам глав.
2024-09-06 ГОСТ принципиальных схем и перечней
2024-09-06 directories for screenshots and schematics
2024-09-06 Лист заключения
2024-09-06 screenshots and schematics
2024-09-06 Строчка [Электронный ресурс]. Вне библиографии.
2024-09-06 Защитил практику на 8.
2024-09-06 Номера в нумерованных списках по СТП
